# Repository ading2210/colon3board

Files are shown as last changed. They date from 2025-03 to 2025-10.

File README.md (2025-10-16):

# colon3board

This is a custom designed mechanical keyboard, created for the the [Hackpad](https://hackpad.hackclub.com/) event. It has a full sized 104 key layout, and a built in OLED display.

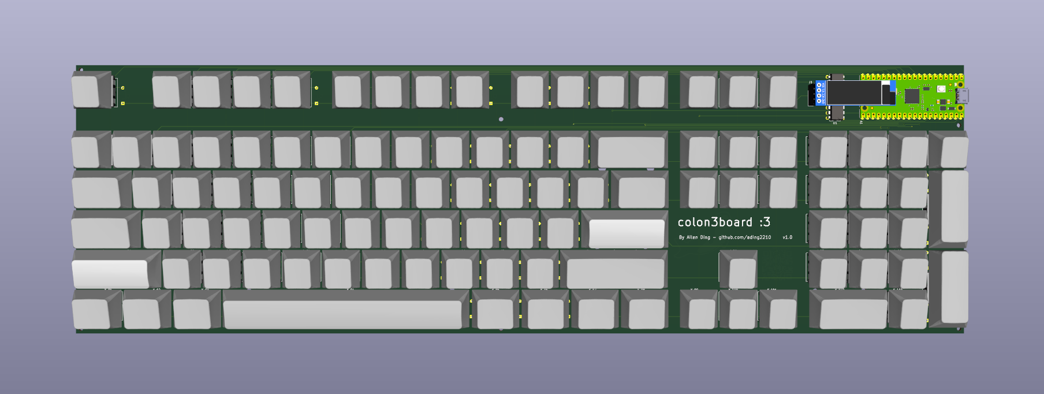
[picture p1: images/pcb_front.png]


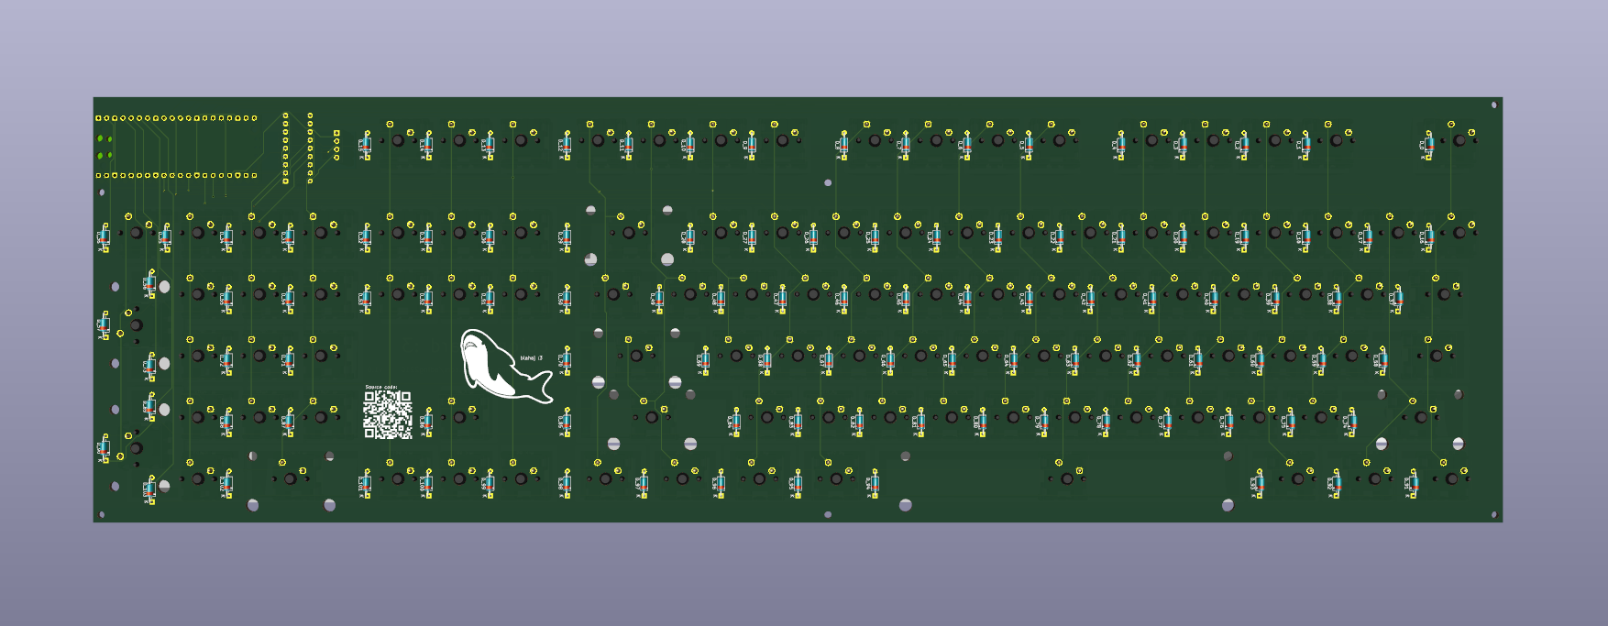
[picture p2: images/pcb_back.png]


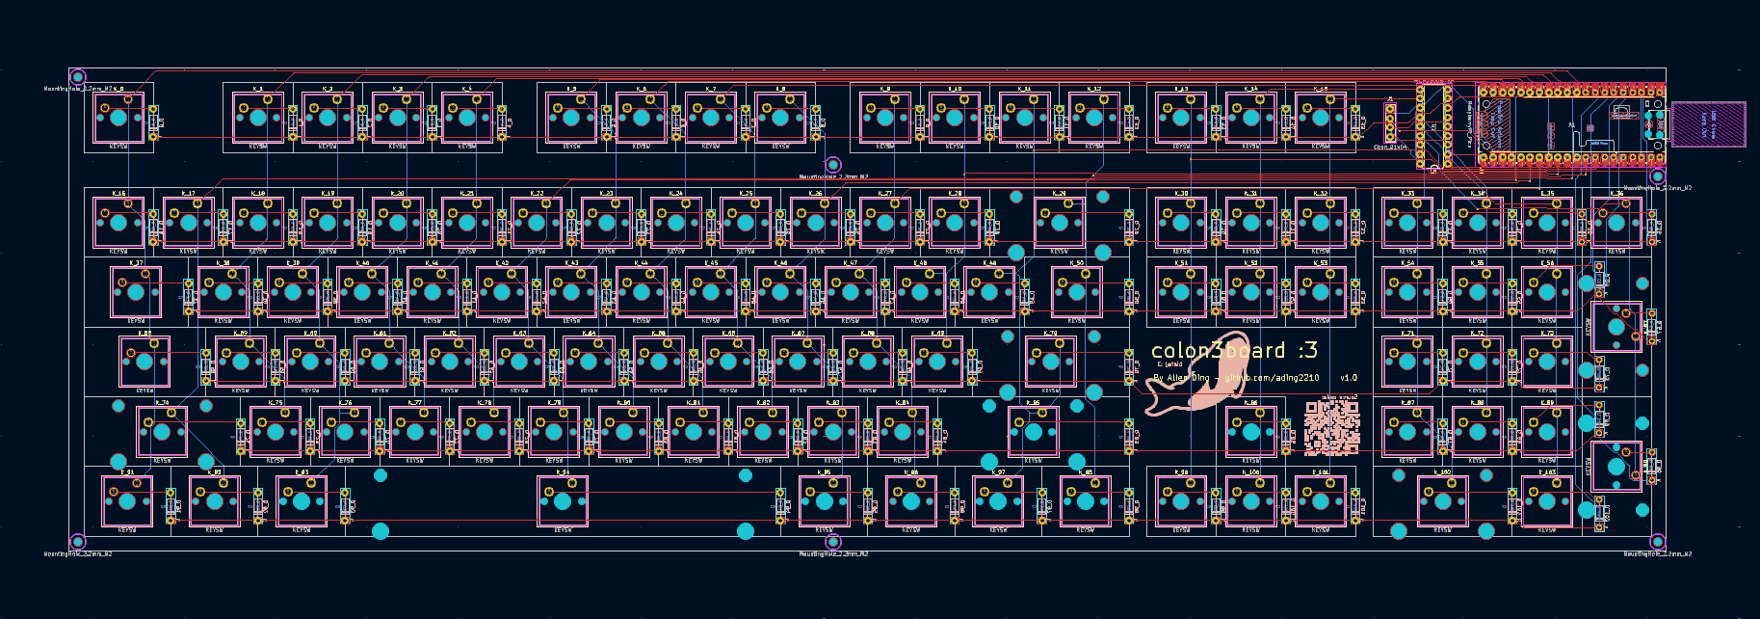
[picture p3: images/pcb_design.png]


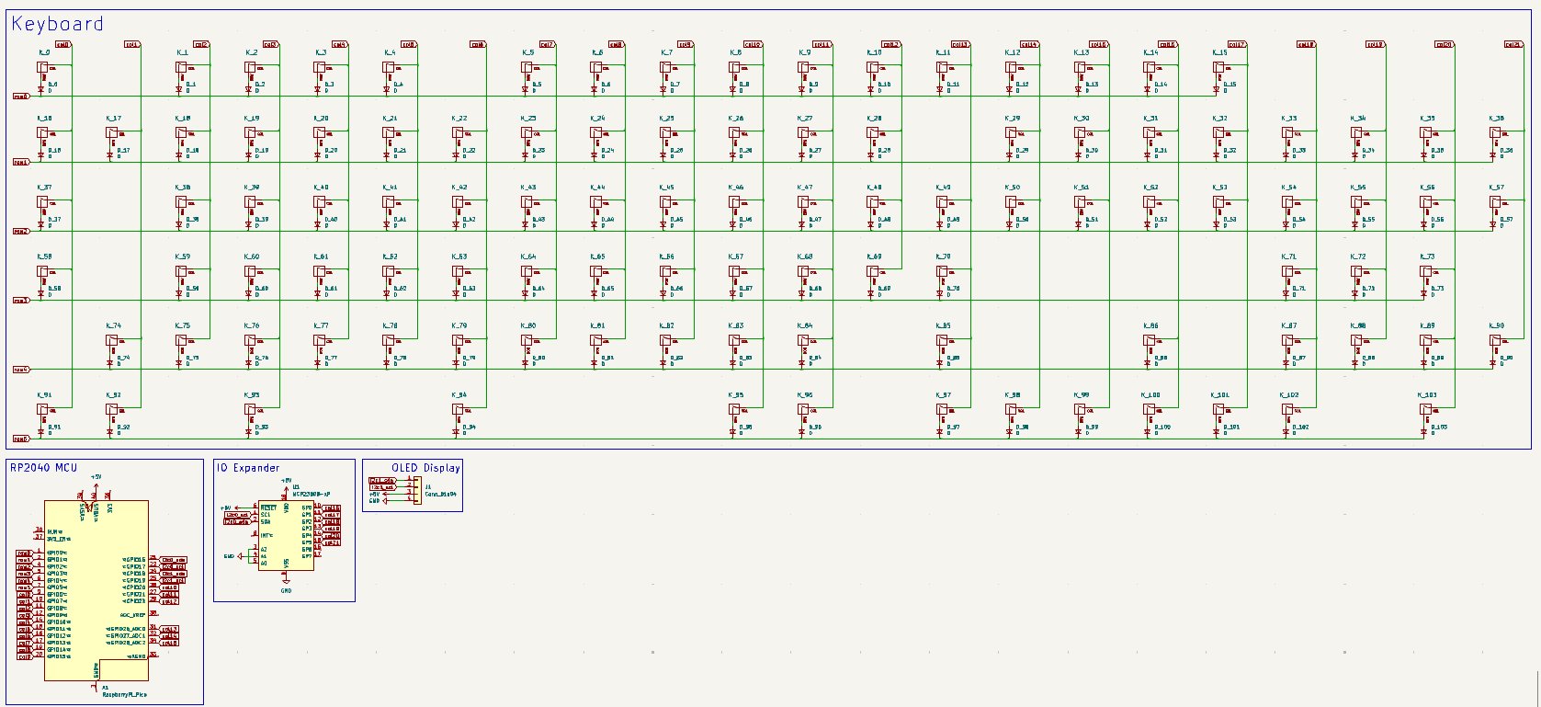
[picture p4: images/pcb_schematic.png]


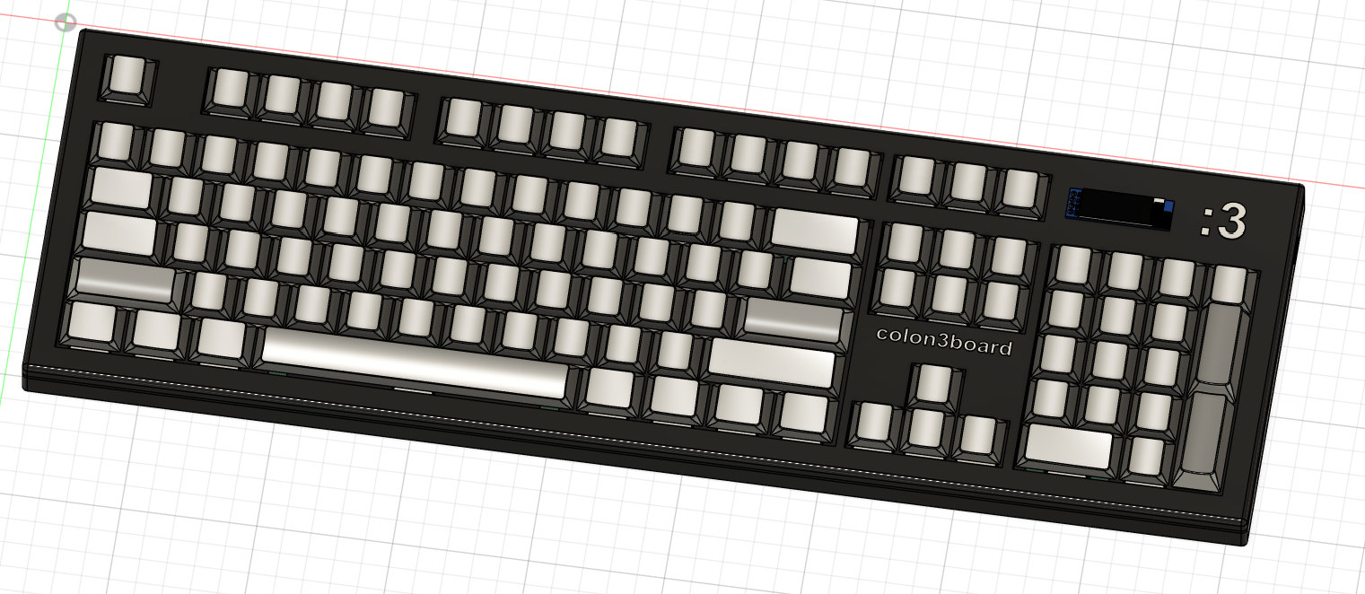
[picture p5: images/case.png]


I designed this so I could get more practice with designing PCBs in KiCad and with modeling larger parts in Fusion 360. Also, I get to have a free keyboard in the end thanks to the grant from Hack Club. 

## BOM

### For PCB:
| Part | Count (needed) | Count (purchased) | Price  | Shipping Cost | Link |
|---|---|---|---|---|---|
| Raspberry Pi Pico | 1 | 0 | $0.00  | $0.00 | https://www.amazon.com/Raspberry-RP2040-microcontroller-Dual-core-Processor-1pc/dp/B0BK9CTMSV |
| SSD1306 128x32 OLED | 1 | 1 | $2.32  | $0.00 | https://www.aliexpress.us/item/3256805123611667.html |
| Cherry MX key switches | 104 | 108 | $32.99 | $0.00 | https://www.amazon.com/Zjmehty-Switches-Mechanical-Pre-Lubed-Pin-Enhanced/dp/B0CF8DWDGF |
| PBT Keycaps | 104 | 139 | $13.99 | $0.00 | https://www.amazon.com/Doubleshot-Mechanical-Keyboard-Compatiability-Keyboads/dp/B0F7H32LKC |
| PCB Mount Stabilizers Kit | 1 | 1 | $9.99  | $0.00 | https://www.amazon.com/GLORIOUS-Stabilizer-Mechanical-Keyboards-Compatible/dp/B09MZKFLXP |
| 1x4 2.54mm vertical female pin header | 1 | 1 | $0.25  | $4.99 | https://www.digikey.com/en/products/detail/adam-tech/RS1-04-G/9829303 |
| 1x4 2.54mm vertical male pin header | 1 | 1 | $0.20  | $0.00 | https://www.digikey.com/en/products/detail/metz-connect-usa-inc/PR20204VBNN/12342903 |
| MCP23008 IO expander | 1 | 1 | $1.54  | $0.00 | https://www.digikey.com/en/products/detail/microchip-technology/MCP23008-E-P/735951 |
| 1N4148 diodes | 104 | 110 | $3.72  | $0.00 | https://www.digikey.com/en/products/detail/onsemi/1N4148-T50A/978509 |
| PCB Fabrication from JLCPCB | 1 | 5 | $25.80 | $52.08 | https://jlcpcb.com/ |

### For Case:
- Case is 3d printed in PLA
- 6x M2x5 screw
- 4x M3x12 screw
- 4x M3x4 heat set inserts

## License

This project is licensed under the GNU GPL v3.

```
ading2210/colon3board - A custom mechanical keyboard
Copyright (C) 2025 ading2210

This program is free software: you can redistribute it and/or modify
it under the terms of the GNU General Public License as published by
the Free Software Foundation, either version 3 of the License, or
(at your option) any later version.

This program is distributed in the hope that it will be useful,
but WITHOUT ANY WARRANTY; without even the implied warranty of
MERCHANTABILITY or FITNESS FOR A PARTICULAR PURPOSE.  See the
GNU General Public License for more details.

You should have received a copy of the GNU General Public License
along with this program.  If not, see <https://www.gnu.org/licenses/>.
```

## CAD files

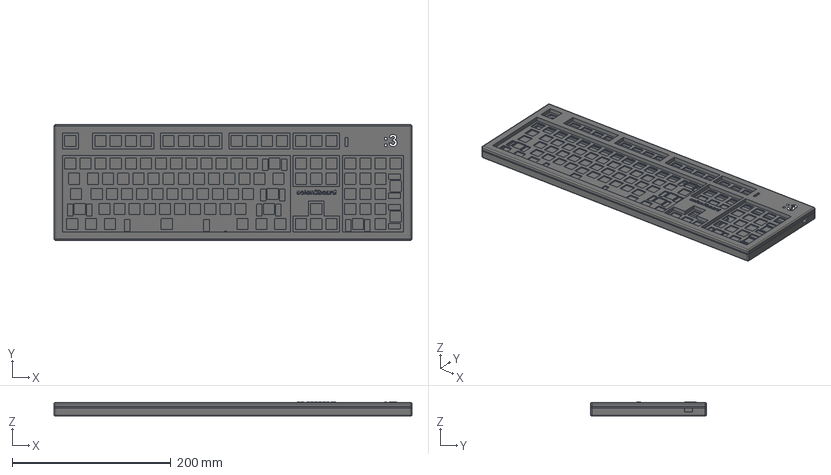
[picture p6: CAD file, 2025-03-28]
CAD/hackboard_case.step
450.6 x 145.8 x 17.5 mm
Case Bottom
Case Plate
Case Top

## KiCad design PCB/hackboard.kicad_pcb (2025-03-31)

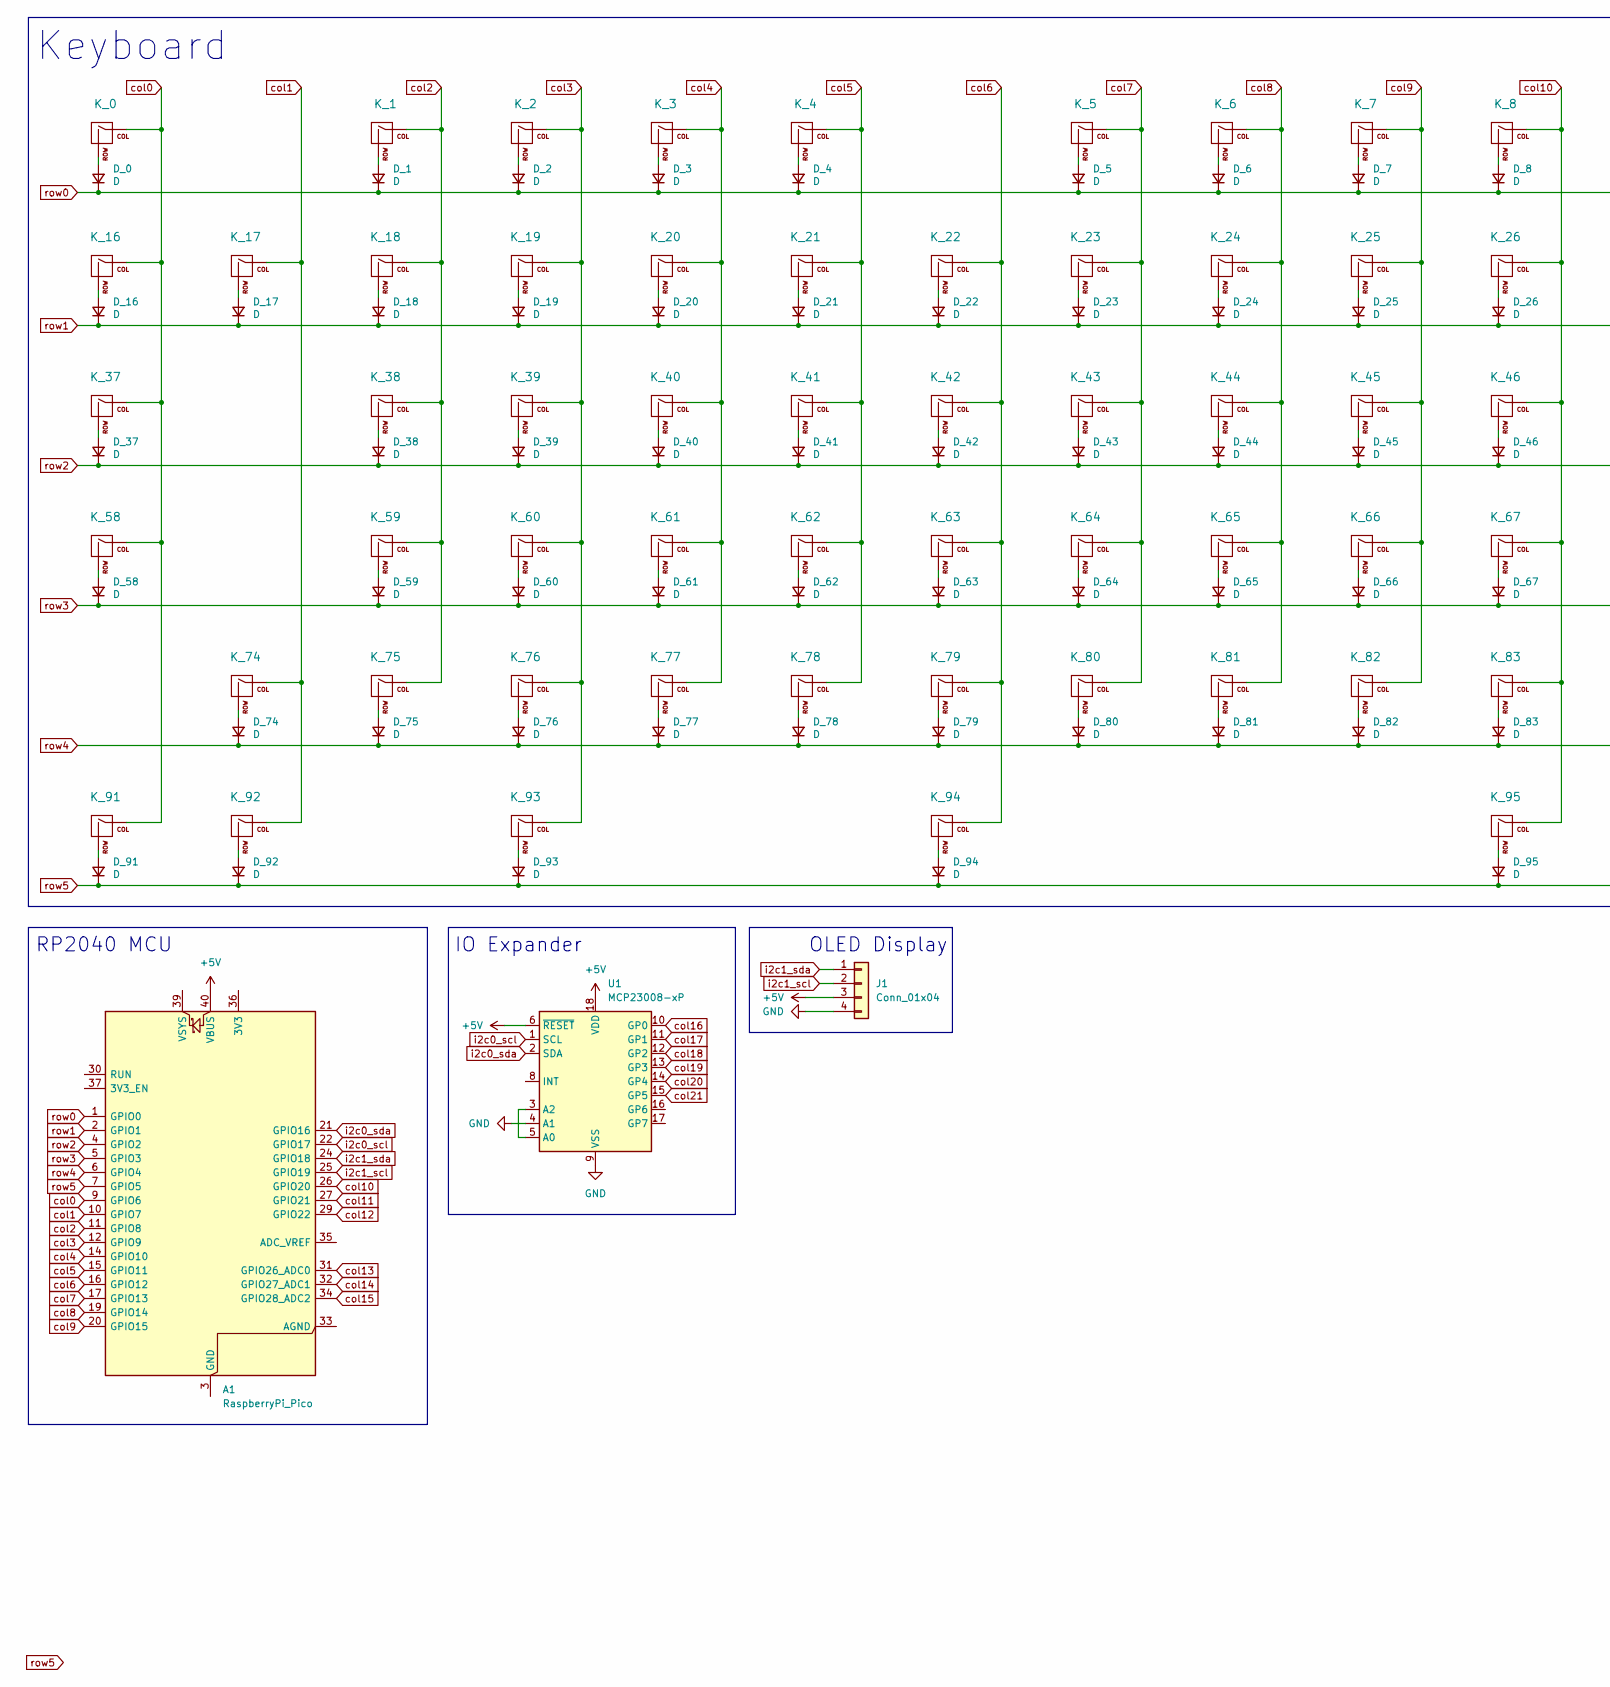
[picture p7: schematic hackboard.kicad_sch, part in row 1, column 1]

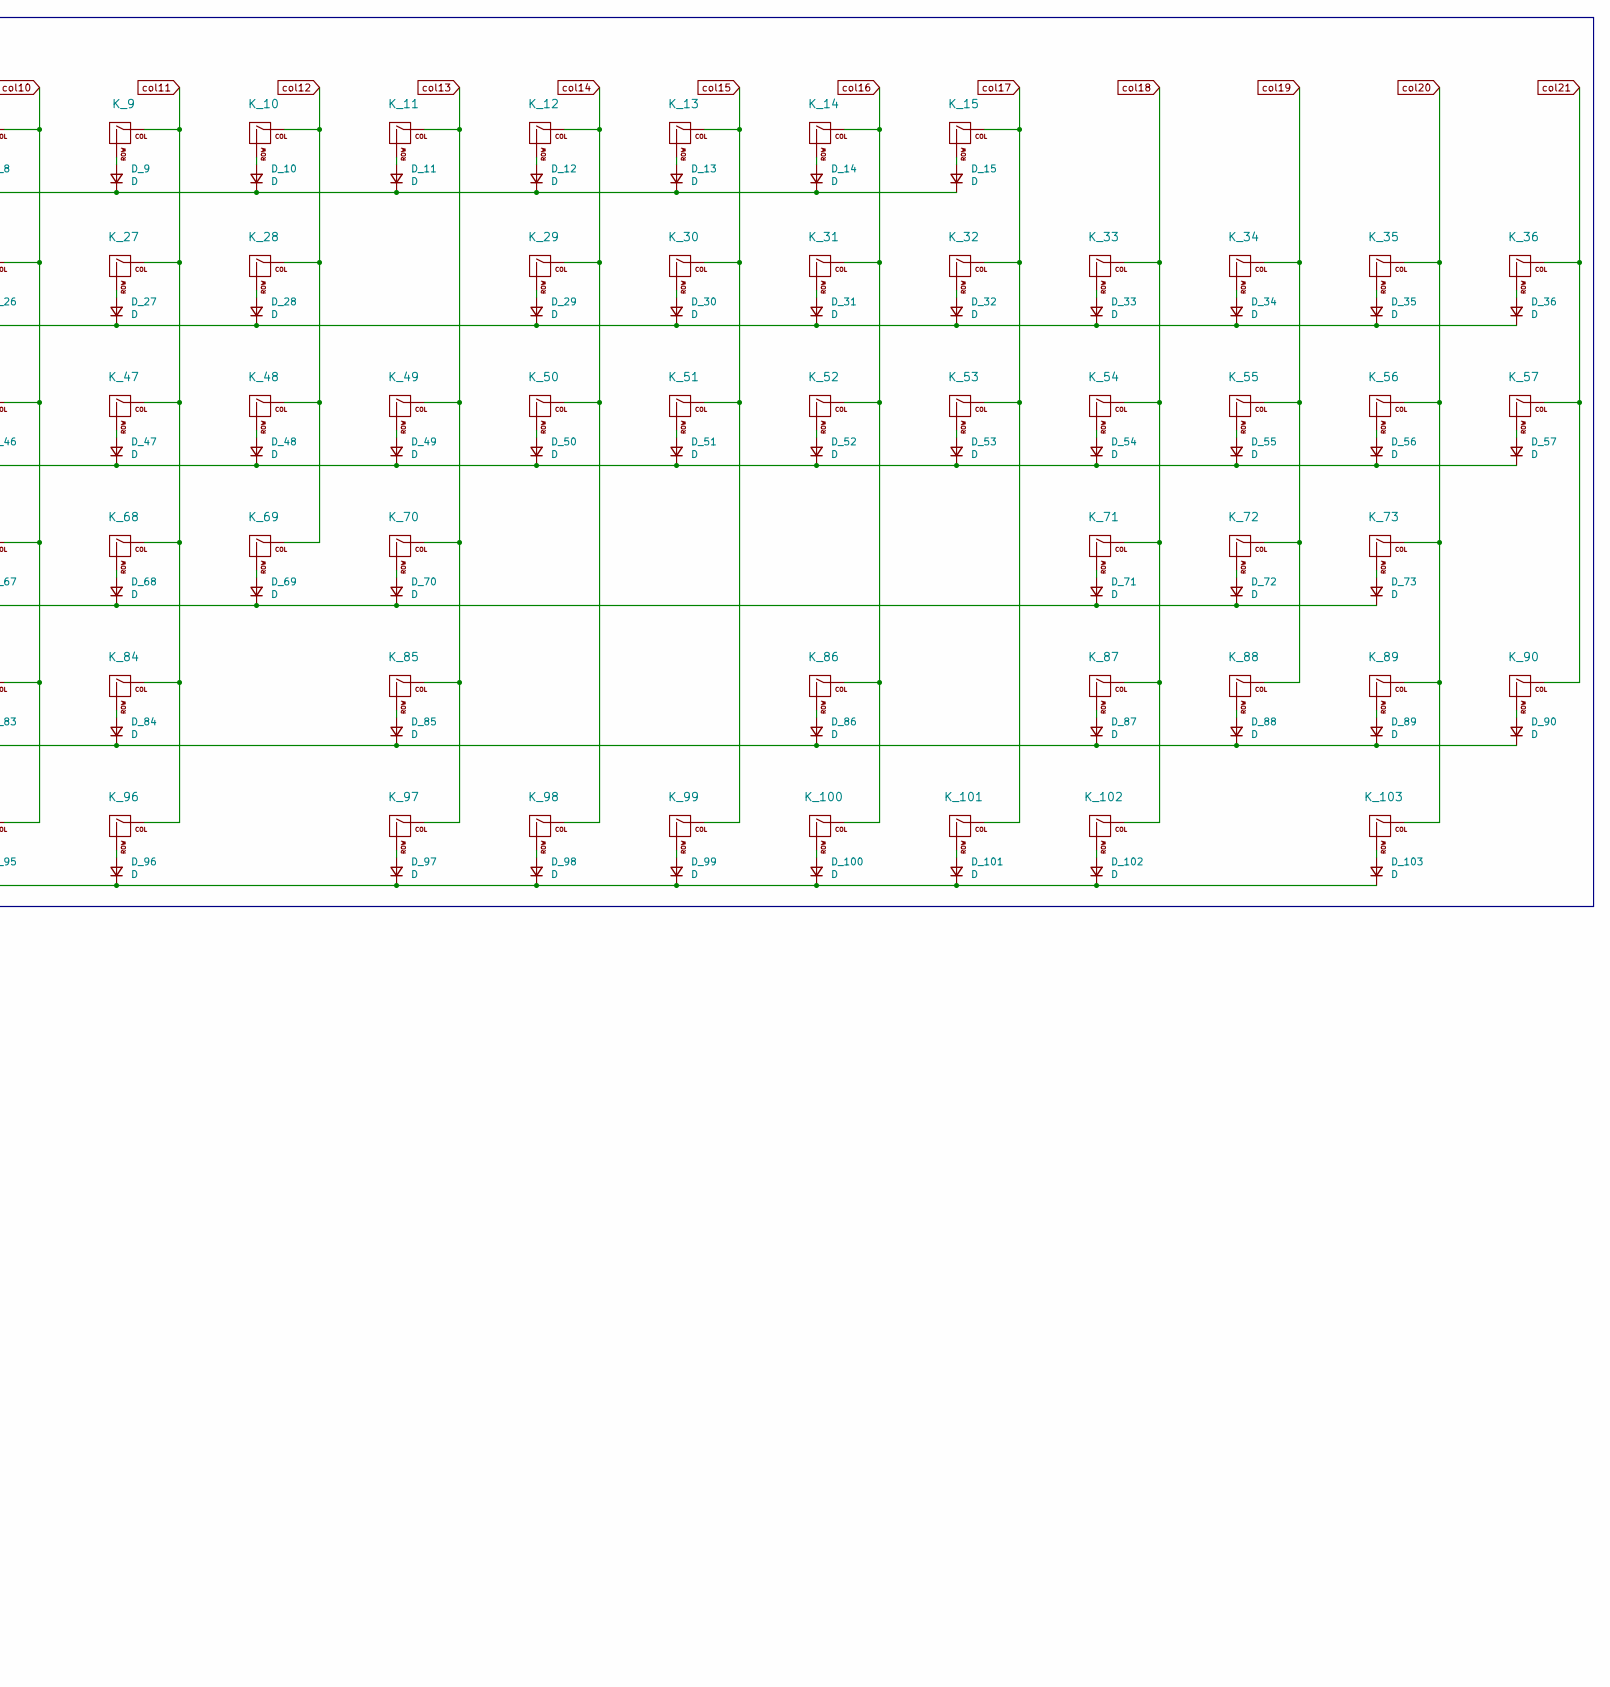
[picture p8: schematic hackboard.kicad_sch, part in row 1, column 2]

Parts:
A1: RaspberryPi_Pico; RaspberryPi_Pico_Common_Unspecified
D_0, D_1, D_2, D_3, D_4, D_5, D_6, D_7, D_8, D_9, D_10, D_11, D_12, D_13, D_14, D_15, D_16, D_17, D_18, D_19, D_20, D_21, D_22, D_23, D_24, D_25, D_26, D_27, D_28, D_29, D_30, D_31, D_32, D_33, D_34, D_35, D_36, D_37, D_38, D_39, D_40, D_41, D_42, D_43, D_44, D_45, D_46, D_47, D_48, D_49, D_50, D_51, D_52, D_53, D_54, D_55, D_56, D_57, D_58, D_59, D_60, D_61, D_62, D_63, D_64, D_65, D_66, D_67, D_68, D_69, D_70, D_71, D_72, D_73, D_74, D_75, D_76, D_77, D_78, D_79, D_80, D_81, D_82, D_83, D_84, D_85, D_86, D_87, D_88, D_89, D_90, D_91, D_92, D_93, D_94, D_95, D_96, D_97, D_98, D_99, D_100, D_101, D_102, D_103: D; D_DO-35_SOD27_P7.62mm_Horizontal
J1: Conn_01x04; PinSocket_1x04_P2.54mm_Vertical_OLED
K_0, K_1, K_2, K_3, K_4, K_5, K_6, K_7, K_8, K_9, K_10, K_11, K_12, K_13, K_14, K_15, K_16, K_17, K_18, K_19, K_20, K_21, K_22, K_23, K_24, K_25, K_26, K_27, K_28, K_30, K_31, K_32, K_33, K_34, K_35, K_36, K_38, K_39, K_40, K_41, K_42, K_43, K_44, K_45, K_46, K_47, K_48, K_49, K_51, K_52, K_53, K_54, K_55, K_56, K_59, K_60, K_61, K_62, K_63, K_64, K_65, K_66, K_67, K_68, K_69, K_71, K_72, K_73, K_75, K_76, K_77, K_78, K_79, K_80, K_81, K_82, K_83, K_84, K_86, K_87, K_88, K_89, K_99, K_100, K_101, K_103: KEYSW; SW_Cherry_MX_1.00u_PCB
K_29, K_102: KEYSW; SW_Cherry_MX_2.00u_PCB
K_37, K_50: KEYSW; SW_Cherry_MX_1.50u_PCB
K_57, K_90: KEYSW; SW_Cherry_MX_2.00u_PCB_r1
K_58: KEYSW; SW_Cherry_MX_1.75u_PCB
K_70, K_74: KEYSW; SW_Cherry_MX_2.25u_PCB
K_85: KEYSW; SW_Cherry_MX_2.75u_PCB
K_91, K_92, K_93, K_95, K_96, K_97, K_98: KEYSW; SW_Cherry_MX_1.25u_PCB
K_94: KEYSW; SW_Cherry_MX_6.25u_PCB
U1: MCP23008-xP; DIP-18_W7.62mm

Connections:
+5V: A1.40 (VBUS), J1.3, U1.6 (~RESET), U1.18 (VDD)
GND: J1.4, U1.4 (A1), U1.9 (VSS)
unnamed: A1.3 (GND), A1.8 (GND), A1.13 (GND), A1.18 (GND), A1.23 (GND), A1.28 (GND), A1.38 (GND)
unnamed: D_0.2 (A), K_0.2 (ROW)
unnamed: D_1.2 (A), K_1.2 (ROW)
unnamed: D_2.2 (A), K_2.2 (ROW)
unnamed: D_3.2 (A), K_3.2 (ROW)
unnamed: D_4.2 (A), K_4.2 (ROW)
unnamed: D_5.2 (A), K_5.2 (ROW)
unnamed: D_6.2 (A), K_6.2 (ROW)
unnamed: D_7.2 (A), K_7.2 (ROW)
unnamed: D_8.2 (A), K_8.2 (ROW)
unnamed: D_9.2 (A), K_9.2 (ROW)
unnamed: D_10.2 (A), K_10.2 (ROW)
unnamed: D_11.2 (A), K_11.2 (ROW)
unnamed: D_12.2 (A), K_12.2 (ROW)
unnamed: D_13.2 (A), K_13.2 (ROW)
unnamed: D_14.2 (A), K_14.2 (ROW)
unnamed: D_15.2 (A), K_15.2 (ROW)
unnamed: D_16.2 (A), K_16.2 (ROW)
unnamed: D_17.2 (A), K_17.2 (ROW)
unnamed: D_18.2 (A), K_18.2 (ROW)
unnamed: D_19.2 (A), K_19.2 (ROW)
unnamed: D_20.2 (A), K_20.2 (ROW)
unnamed: D_21.2 (A), K_21.2 (ROW)
unnamed: D_22.2 (A), K_22.2 (ROW)
unnamed: D_23.2 (A), K_23.2 (ROW)
unnamed: D_24.2 (A), K_24.2 (ROW)
unnamed: D_25.2 (A), K_25.2 (ROW)
unnamed: D_26.2 (A), K_26.2 (ROW)
unnamed: D_27.2 (A), K_27.2 (ROW)
unnamed: D_28.2 (A), K_28.2 (ROW)
unnamed: D_29.2 (A), K_29.2 (ROW)
unnamed: D_30.2 (A), K_30.2 (ROW)
unnamed: D_31.2 (A), K_31.2 (ROW)
unnamed: D_32.2 (A), K_32.2 (ROW)
unnamed: D_33.2 (A), K_33.2 (ROW)
unnamed: D_34.2 (A), K_34.2 (ROW)
unnamed: D_35.2 (A), K_35.2 (ROW)
unnamed: D_36.2 (A), K_36.2 (ROW)
unnamed: D_37.2 (A), K_37.2 (ROW)
unnamed: D_38.2 (A), K_38.2 (ROW)
unnamed: D_39.2 (A), K_39.2 (ROW)
unnamed: D_40.2 (A), K_40.2 (ROW)
unnamed: D_41.2 (A), K_41.2 (ROW)
unnamed: D_42.2 (A), K_42.2 (ROW)
unnamed: D_43.2 (A), K_43.2 (ROW)
unnamed: D_44.2 (A), K_44.2 (ROW)
unnamed: D_45.2 (A), K_45.2 (ROW)
unnamed: D_46.2 (A), K_46.2 (ROW)
unnamed: D_47.2 (A), K_47.2 (ROW)
unnamed: D_48.2 (A), K_48.2 (ROW)
unnamed: D_49.2 (A), K_49.2 (ROW)
unnamed: D_50.2 (A), K_50.2 (ROW)
unnamed: D_51.2 (A), K_51.2 (ROW)
unnamed: D_52.2 (A), K_52.2 (ROW)
unnamed: D_53.2 (A), K_53.2 (ROW)
unnamed: D_54.2 (A), K_54.2 (ROW)
unnamed: D_55.2 (A), K_55.2 (ROW)
unnamed: D_56.2 (A), K_56.2 (ROW)
unnamed: D_57.2 (A), K_57.2 (ROW)
unnamed: D_58.2 (A), K_58.2 (ROW)
unnamed: D_59.2 (A), K_59.2 (ROW)
unnamed: D_60.2 (A), K_60.2 (ROW)
unnamed: D_61.2 (A), K_61.2 (ROW)
unnamed: D_62.2 (A), K_62.2 (ROW)
unnamed: D_63.2 (A), K_63.2 (ROW)
unnamed: D_64.2 (A), K_64.2 (ROW)
unnamed: D_65.2 (A), K_65.2 (ROW)
unnamed: D_66.2 (A), K_66.2 (ROW)
unnamed: D_67.2 (A), K_67.2 (ROW)
unnamed: D_68.2 (A), K_68.2 (ROW)
unnamed: D_69.2 (A), K_69.2 (ROW)
unnamed: D_70.2 (A), K_70.2 (ROW)
unnamed: D_71.2 (A), K_71.2 (ROW)
unnamed: D_72.2 (A), K_72.2 (ROW)
unnamed: D_73.2 (A), K_73.2 (ROW)
unnamed: D_74.2 (A), K_74.2 (ROW)
unnamed: D_75.2 (A), K_75.2 (ROW)
unnamed: D_76.2 (A), K_76.2 (ROW)
unnamed: D_77.2 (A), K_77.2 (ROW)
unnamed: D_78.2 (A), K_78.2 (ROW)
unnamed: D_79.2 (A), K_79.2 (ROW)
unnamed: D_80.2 (A), K_80.2 (ROW)
unnamed: D_81.2 (A), K_81.2 (ROW)
unnamed: D_82.2 (A), K_82.2 (ROW)
unnamed: D_83.2 (A), K_83.2 (ROW)
unnamed: D_84.2 (A), K_84.2 (ROW)
unnamed: D_85.2 (A), K_85.2 (ROW)
unnamed: D_86.2 (A), K_86.2 (ROW)
unnamed: D_87.2 (A), K_87.2 (ROW)
unnamed: D_88.2 (A), K_88.2 (ROW)
unnamed: D_89.2 (A), K_89.2 (ROW)
unnamed: D_90.2 (A), K_90.2 (ROW)
unnamed: D_91.2 (A), K_91.2 (ROW)
unnamed: D_92.2 (A), K_92.2 (ROW)
unnamed: D_93.2 (A), K_93.2 (ROW)
unnamed: D_94.2 (A), K_94.2 (ROW)
unnamed: D_95.2 (A), K_95.2 (ROW)
unnamed: D_96.2 (A), K_96.2 (ROW)
unnamed: D_97.2 (A), K_97.2 (ROW)
unnamed: D_98.2 (A), K_98.2 (ROW)
unnamed: D_99.2 (A), K_99.2 (ROW)
unnamed: D_100.2 (A), K_100.2 (ROW)
unnamed: D_101.2 (A), K_101.2 (ROW)
unnamed: D_102.2 (A), K_102.2 (ROW)
unnamed: D_103.2 (A), K_103.2 (ROW)
unnamed: U1.3 (A2), U1.5 (A0)
col0: A1.9 (GPIO6), K_0.1 (COL), K_16.1 (COL), K_37.1 (COL), K_58.1 (COL), K_91.1 (COL)
col1: A1.10 (GPIO7), K_17.1 (COL), K_74.1 (COL), K_92.1 (COL)
col2: A1.11 (GPIO8), K_1.1 (COL), K_18.1 (COL), K_38.1 (COL), K_59.1 (COL), K_75.1 (COL)
col3: A1.12 (GPIO9), K_2.1 (COL), K_19.1 (COL), K_39.1 (COL), K_60.1 (COL), K_76.1 (COL), K_93.1 (COL)
col4: A1.14 (GPIO10), K_3.1 (COL), K_20.1 (COL), K_40.1 (COL), K_61.1 (COL), K_77.1 (COL)
col5: A1.15 (GPIO11), K_4.1 (COL), K_21.1 (COL), K_41.1 (COL), K_62.1 (COL), K_78.1 (COL)
col6: A1.16 (GPIO12), K_22.1 (COL), K_42.1 (COL), K_63.1 (COL), K_79.1 (COL), K_94.1 (COL)
col7: A1.17 (GPIO13), K_5.1 (COL), K_23.1 (COL), K_43.1 (COL), K_64.1 (COL), K_80.1 (COL)
col8: A1.19 (GPIO14), K_6.1 (COL), K_24.1 (COL), K_44.1 (COL), K_65.1 (COL), K_81.1 (COL)
col9: A1.20 (GPIO15), K_7.1 (COL), K_25.1 (COL), K_45.1 (COL), K_66.1 (COL), K_82.1 (COL)
col10: A1.26 (GPIO20), K_8.1 (COL), K_26.1 (COL), K_46.1 (COL), K_67.1 (COL), K_83.1 (COL), K_95.1 (COL)
col11: A1.27 (GPIO21), K_9.1 (COL), K_27.1 (COL), K_47.1 (COL), K_68.1 (COL), K_84.1 (COL), K_96.1 (COL)
col12: A1.29 (GPIO22), K_10.1 (COL), K_28.1 (COL), K_48.1 (COL), K_69.1 (COL)
col13: A1.31 (GPIO26_ADC0), K_11.1 (COL), K_49.1 (COL), K_70.1 (COL), K_85.1 (COL), K_97.1 (COL)
col14: A1.32 (GPIO27_ADC1), K_12.1 (COL), K_29.1 (COL), K_50.1 (COL), K_98.1 (COL)
col15: A1.34 (GPIO28_ADC2), K_13.1 (COL), K_30.1 (COL), K_51.1 (COL), K_99.1 (COL)
col16: K_14.1 (COL), K_31.1 (COL), K_52.1 (COL), K_86.1 (COL), K_100.1 (COL), U1.10 (GP0)
col17: K_15.1 (COL), K_32.1 (COL), K_53.1 (COL), K_101.1 (COL), U1.11 (GP1)
col18: K_33.1 (COL), K_54.1 (COL), K_71.1 (COL), K_87.1 (COL), K_102.1 (COL), U1.12 (GP2)
col19: K_34.1 (COL), K_55.1 (COL), K_72.1 (COL), K_88.1 (COL), U1.13 (GP3)
col20: K_35.1 (COL), K_56.1 (COL), K_73.1 (COL), K_89.1 (COL), K_103.1 (COL), U1.14 (GP4)
col21: K_36.1 (COL), K_57.1 (COL), K_90.1 (COL), U1.15 (GP5)
i2c0_scl: A1.22 (GPIO17), U1.1 (SCL)
i2c0_sda: A1.21 (GPIO16), U1.2 (SDA)
i2c1_scl: A1.25 (GPIO19), J1.2
i2c1_sda: A1.24 (GPIO18), J1.1
row0: A1.1 (GPIO0), D_0.1 (K), D_1.1 (K), D_2.1 (K), D_3.1 (K), D_4.1 (K), D_5.1 (K), D_6.1 (K), D_7.1 (K), D_8.1 (K), D_9.1 (K), D_10.1 (K), D_11.1 (K), D_12.1 (K), D_13.1 (K), D_14.1 (K), D_15.1 (K)
row1: A1.2 (GPIO1), D_16.1 (K), D_17.1 (K), D_18.1 (K), D_19.1 (K), D_20.1 (K), D_21.1 (K), D_22.1 (K), D_23.1 (K), D_24.1 (K), D_25.1 (K), D_26.1 (K), D_27.1 (K), D_28.1 (K), D_29.1 (K), D_30.1 (K), D_31.1 (K), D_32.1 (K), D_33.1 (K), D_34.1 (K), D_35.1 (K), D_36.1 (K)
row2: A1.4 (GPIO2), D_37.1 (K), D_38.1 (K), D_39.1 (K), D_40.1 (K), D_41.1 (K), D_42.1 (K), D_43.1 (K), D_44.1 (K), D_45.1 (K), D_46.1 (K), D_47.1 (K), D_48.1 (K), D_49.1 (K), D_50.1 (K), D_51.1 (K), D_52.1 (K), D_53.1 (K), D_54.1 (K), D_55.1 (K), D_56.1 (K), D_57.1 (K)
row3: A1.5 (GPIO3), D_58.1 (K), D_59.1 (K), D_60.1 (K), D_61.1 (K), D_62.1 (K), D_63.1 (K), D_64.1 (K), D_65.1 (K), D_66.1 (K), D_67.1 (K), D_68.1 (K), D_69.1 (K), D_70.1 (K), D_71.1 (K), D_72.1 (K), D_73.1 (K)
row4: A1.6 (GPIO4), D_74.1 (K), D_75.1 (K), D_76.1 (K), D_77.1 (K), D_78.1 (K), D_79.1 (K), D_80.1 (K), D_81.1 (K), D_82.1 (K), D_83.1 (K), D_84.1 (K), D_85.1 (K), D_86.1 (K), D_87.1 (K), D_88.1 (K), D_89.1 (K), D_90.1 (K)
row5: A1.7 (GPIO5), D_91.1 (K), D_92.1 (K), D_93.1 (K), D_94.1 (K), D_95.1 (K), D_96.1 (K), D_97.1 (K), D_98.1 (K), D_99.1 (K), D_100.1 (K), D_101.1 (K), D_102.1 (K), D_103.1 (K)

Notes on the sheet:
Keyboard
IO Expander
RP2040 MCU
OLED Display

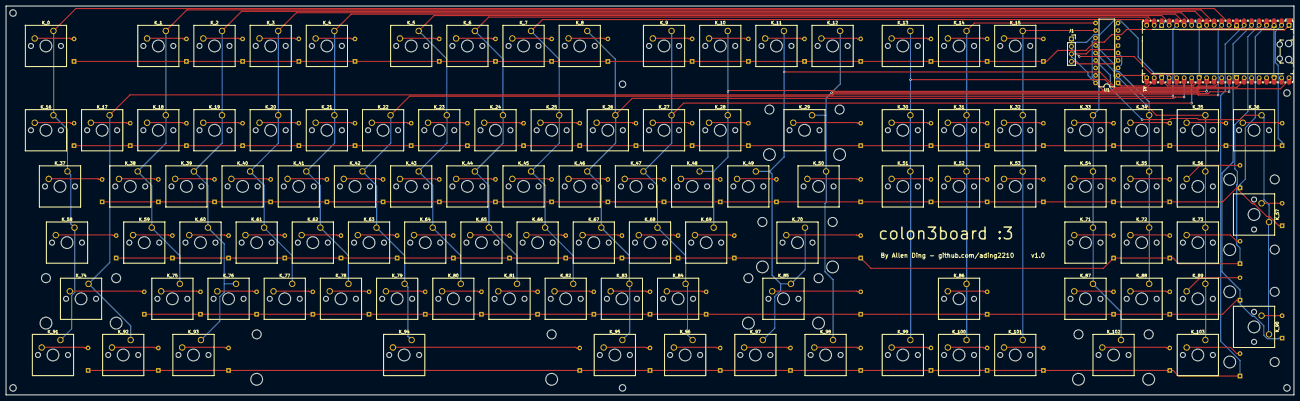
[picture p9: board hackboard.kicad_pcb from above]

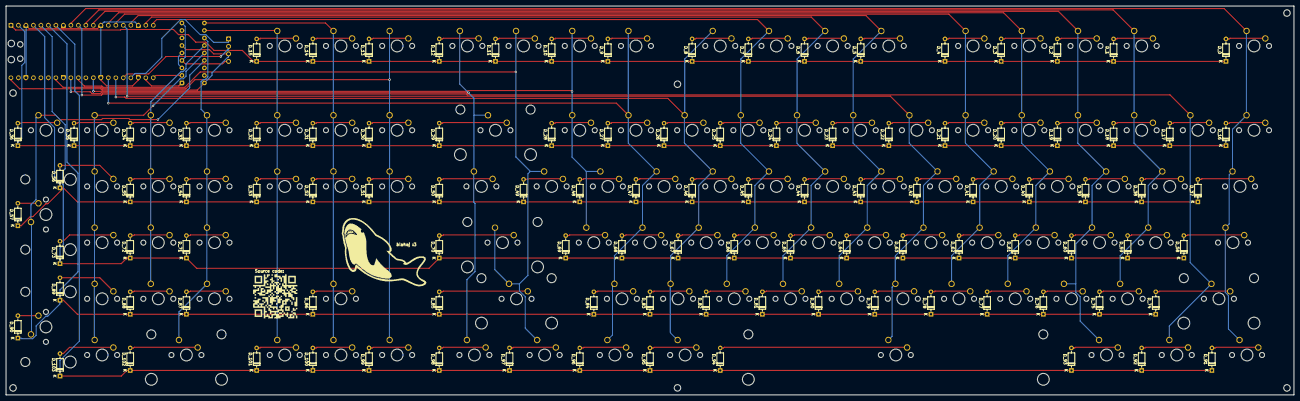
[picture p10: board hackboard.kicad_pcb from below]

Board: 2 copper layers, 436.6 x 131.8 mm, 219 parts (106 on the bottom side), 140 nets.

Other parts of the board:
G1, G2: LOGO
H1, H2, H3, H4, H5, H6: MountingHole_2.2mm_M2

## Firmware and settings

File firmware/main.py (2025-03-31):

import board
import busio
import digitalio

from kmk.kmk_keyboard import KMKKeyboard
from kmk.scanners.keypad import MatrixScanner
from kmk.extensions.international import International
from kmk.keys import KC

from adafruit_mcp230xx.mcp23008 import MCP23008

#set up io expander
i2c = busio.I2C(board.SCL1, board.SDA1)
mcp = MCP23008(i2c)
mcp_pins = [mcp.get_pin(i) for i in range(6)]

#set up keyboard
keyboard = KMKKeyboard()
macros = Macros()
keyboard.modules.append(macros)
keyboard.extensions.append(International())

#define row/col pins
COL_PINS = [
  board.GP6, board.GP7, board.GP8, board.GP9, board.GP10, #col0 - col4
  board.GP11, board.GP12, board.GP13, board.GP14, board.GP15, #col5 - col9
  board.GP20, board.GP21, board.GP22, board.GP26, board.GP27, #col10 - col14
  board.GP28, mcp_pins[0], mcp_pins[1], mcp_pins[2], mcp_pins[3], #col15 - col19
  mcp_pins[4], mcp_pins[5] #col20-col21
]
ROW_PINS = [
  board.GP0, board.GP1, board.GP2, board.GP3, board.GP4, #row0-row4
  board.GP5 #row5
]

#setup key matrix
keyboard.matrix = MatrixScanner(
  column_pins = COL_PINS,
  row_pins = ROW_PINS
)

#alias for cleaner key map
_____ = KC.NO

#setup key map
keyboard.keymap = [
  [KC.ESC,  _____,   KC.F1, KC.F2,   KC.F3, KC.F4, _____,  KC.F5, KC.F6, KC.F7,   KC.F8,   KC.F9,   KC.F10,  KC.11,   KC.F12,   KC.PSCR, KC.SLCK, KC.PAUS, _____,   _____,   _____,   _____  ],
  [KC.GRV,  KC.N1,   KC.N2, KC.N3,   KC.N4, KC.N5, KC.N6,  KC.N7, KC.N8, KC.N9,   KC.N0,   KC.MINS, KC.EQL,  _____,   KC.BSPC,  KC.INS,  KC.HOME, KC.PGUP, KC.NLCK, KC.PSLS, KC.PAST, KC.PMNS],
  [KC.TAB,  _____,   KC.Q,  KC.W,    KC.E,  KC.R,  KC.T,   KC.Y,  KC.U,  KC.I,    KC.O,    KC.P,    KC.LBRC, KC.RBRC, KC.BSLC,  KC.DEL,  KC.END,  KC.PGDN, KC.P7,   KC.P8,   KC.P9,   KC.PPLS],
  [KC.CAPS, _____,   KC.A,  KC.S,    KC.D,  KC.F,  KC.G,   KC.H,  KC.J,  KC.K,    KC.L,    KC.SCLN, KC.QUOT, KC.ENT,  _____,    _____,   _____,   _____,   KC.P4,   KC.P5,   KC.P6,   _____  ],
  [_____,   KC.LSFT, KC.Z,  KC.X,    KC.C,  KC.V,  KC.B,   KC.N,  KC.M,  KC.COMM, KC.DOT,  KC.SLSH, _____,   KC.RSFT, _____,    _____,   KC.UP,   _____,   KC.P1,   KC.P2,   KC.P3,   KC.PENT],
  [KC.LCTL, KC.LWIN, _____, KC.LALT, _____, _____, KC.SPC, _____, _____, _____,   KC.RALT, KC.RWIN, _____,   KC.MENU, KC.RCTL,  KC.LEFT, KC.DOWN, KC.RGHT, KC.P0,   _____,   KC.PDOT, _____  ]
]

if __name__ == "__main__":
  keyboard.go()

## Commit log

2025-03-24 add initial kicad files
    [hackboard.kicad_pcb, hackboard.kicad_sch, hackboard.sch]
2025-03-25 add submodules for pi pico, files for oled
    [hackboard.kicad_pcb, hackboard.kicad_sch]
2025-03-25 add pcb routing and 3d model
    [hackboard.kicad_pcb]
2025-03-25 add 3d models for all key switches and components
    [hackboard.kicad_pcb, hackboard.kicad_sch]
2025-03-27 silkscreen art and mounting holes
    [hackboard.kicad_pcb, hackboard.kicad_sch]
2025-03-28 initial version of case cad model
    [hackboard_case.step]
2025-03-31 fix missing row5 connection on pcb
    [hackboard.kicad_pcb, hackboard.kicad_sch]
2025-03-31 add license and bom
2025-03-31 add images to readme
    [hackboard.kicad_sch]
2025-10-13 update bom and add production files
    [BOM.csv, BOM.ods]
2025-10-16 update bom
    [BOM.csv, BOM.ods]
